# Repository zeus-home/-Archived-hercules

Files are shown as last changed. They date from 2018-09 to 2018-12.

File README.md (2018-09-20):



# Hercules

Hercules is responsible for actually executing the changes in the state of the devices according to the data collected by mercury and decision taken by the tesseract.

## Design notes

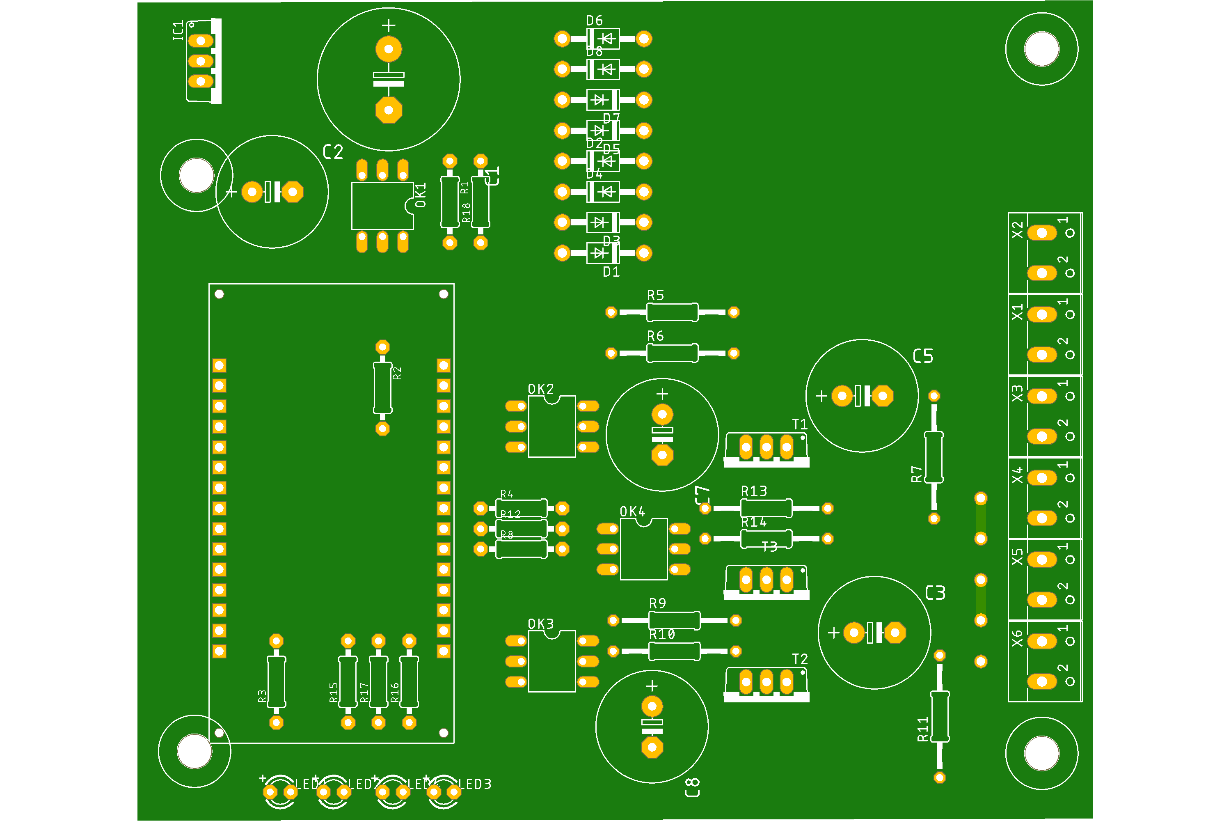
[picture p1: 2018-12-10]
hardware/iotssbv2_t.png

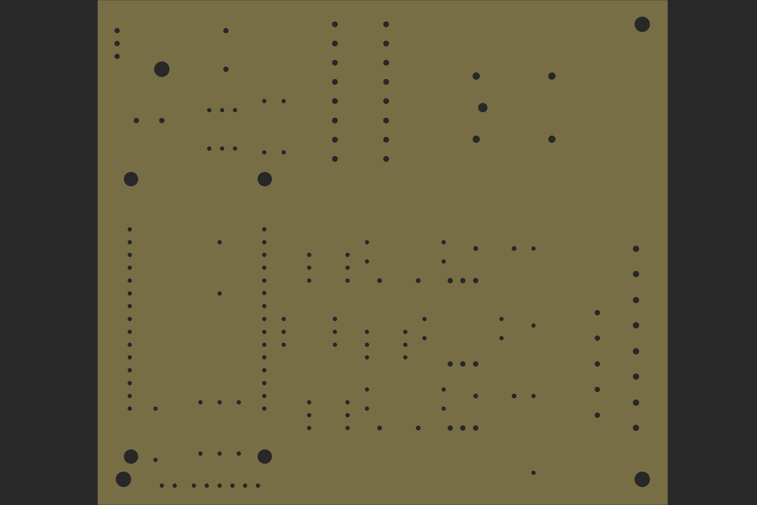
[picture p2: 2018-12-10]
hardware/iotssb_d.png

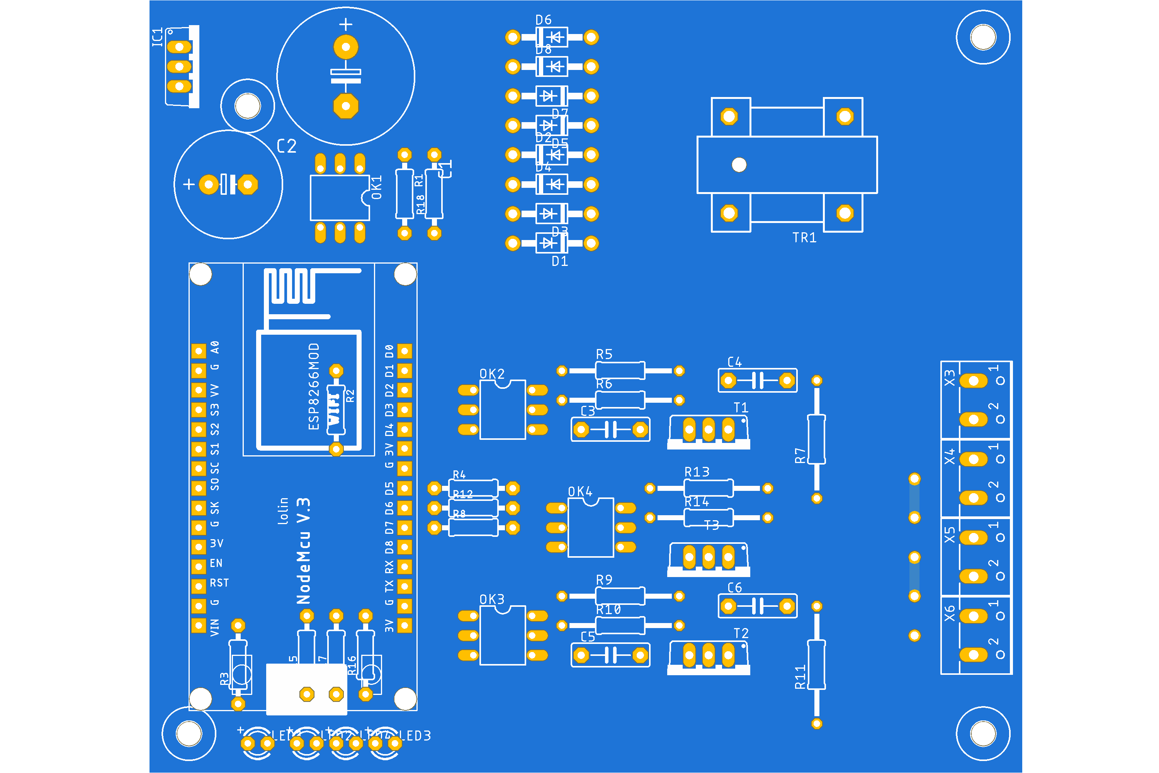
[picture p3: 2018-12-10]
hardware/iotssb_t.png

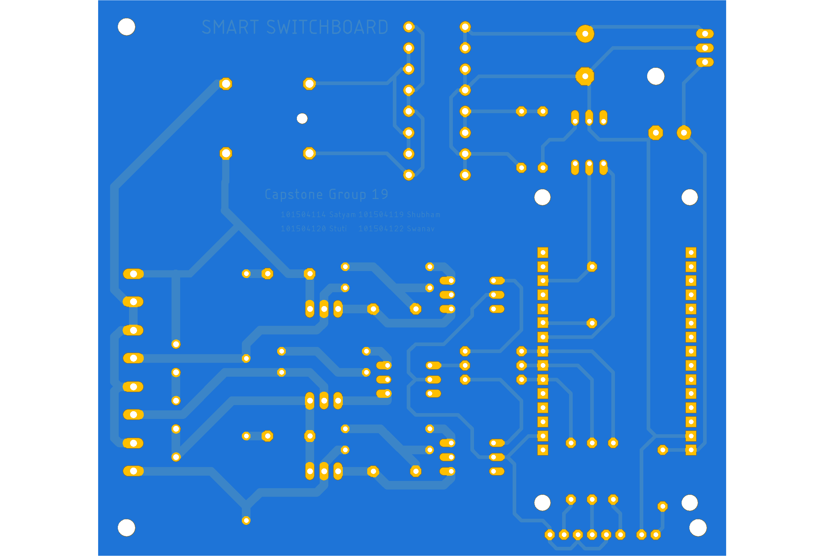
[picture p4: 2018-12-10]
hardware/iotssb_b.png

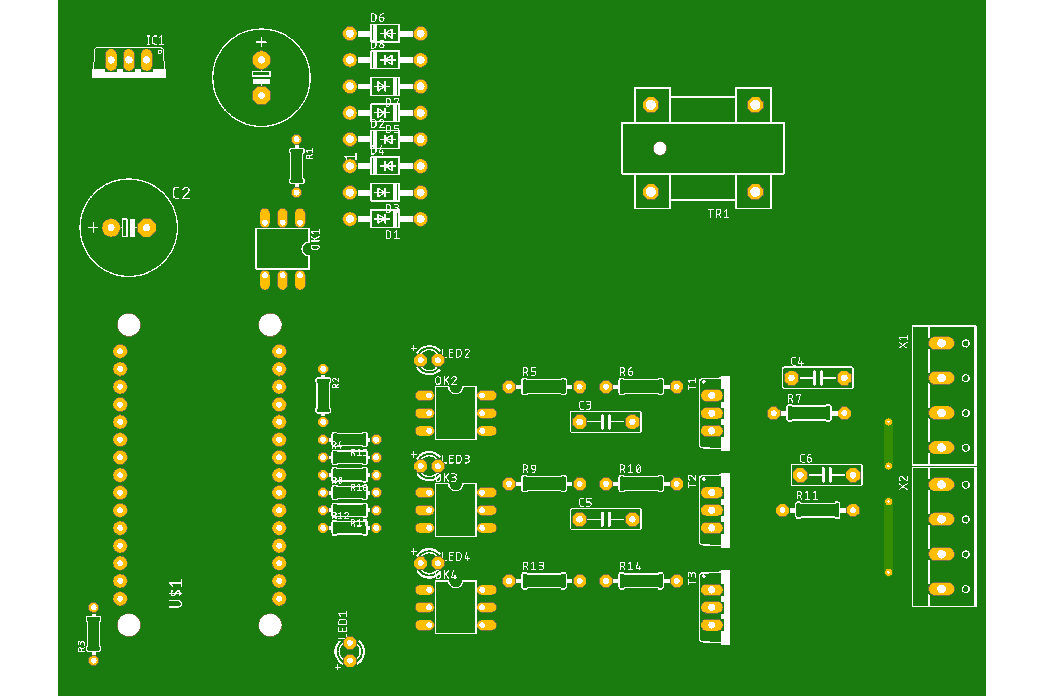
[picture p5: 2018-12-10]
hardware/v2.png

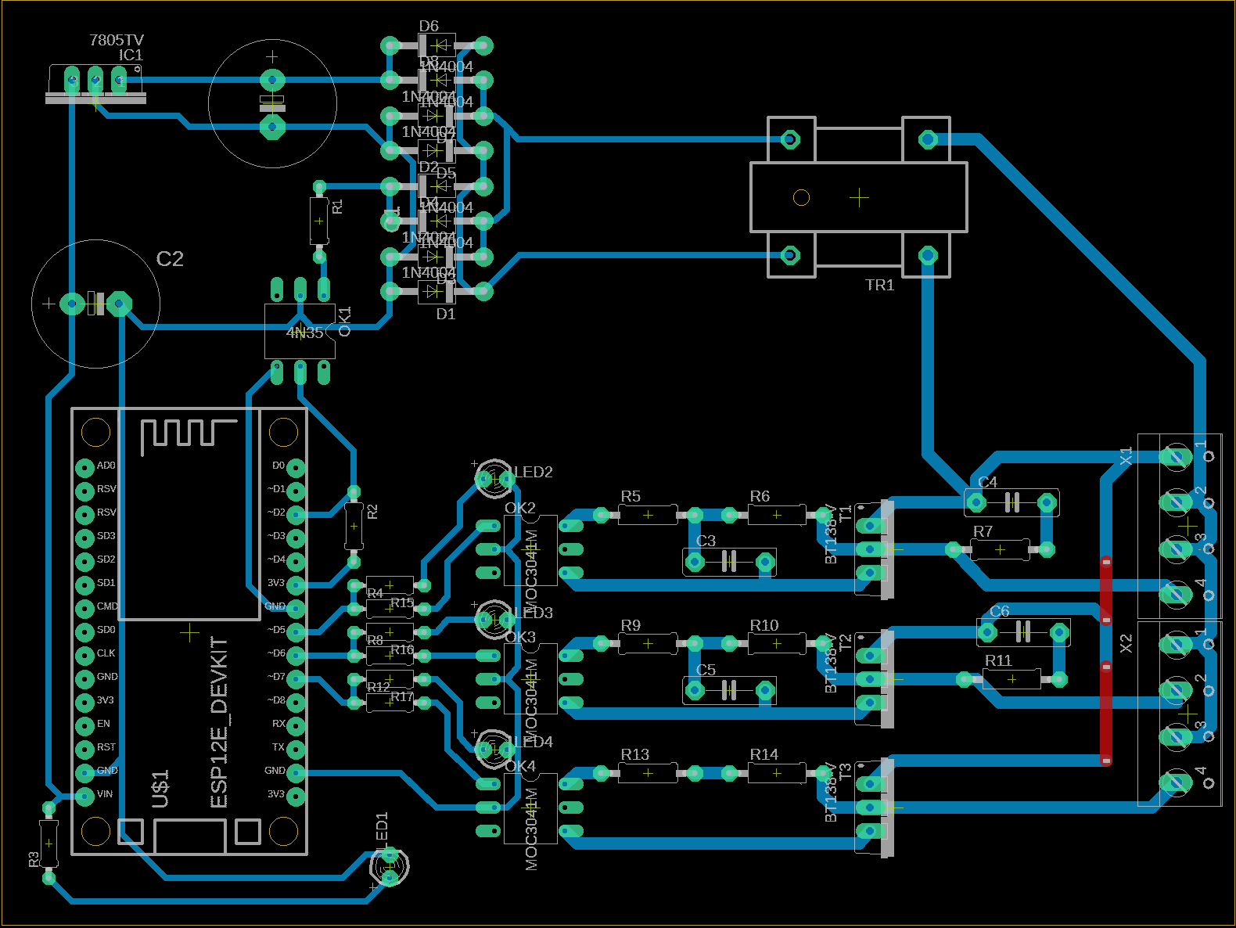
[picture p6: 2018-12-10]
hardware/PCB.png

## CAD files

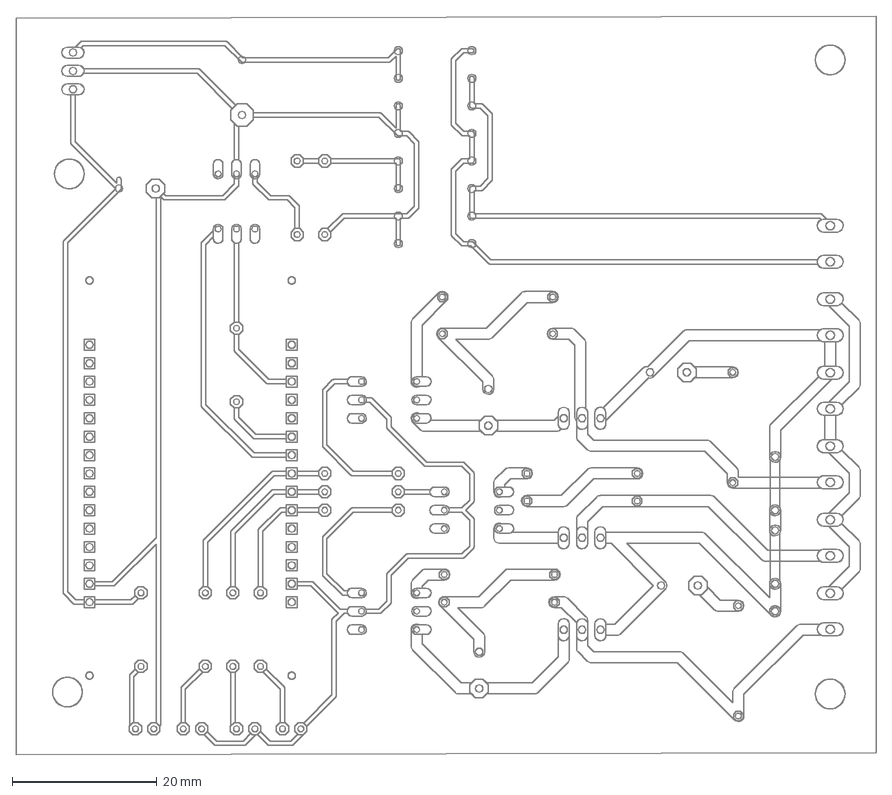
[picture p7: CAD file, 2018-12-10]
hardware/CAMOutputs/DrawingFiles/iotssb.dxf
118.9 x 102.0 mm

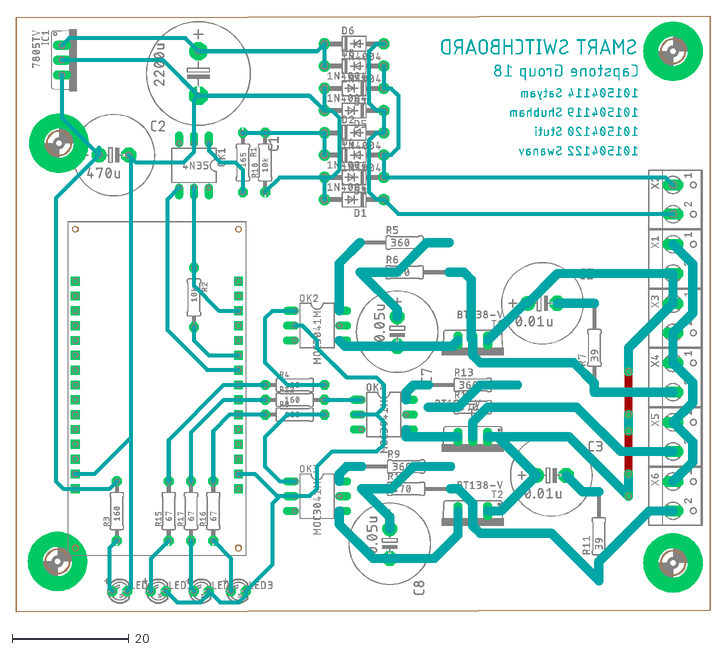
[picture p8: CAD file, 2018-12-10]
hardware/iotssb.dxf
118.9 x 102.0

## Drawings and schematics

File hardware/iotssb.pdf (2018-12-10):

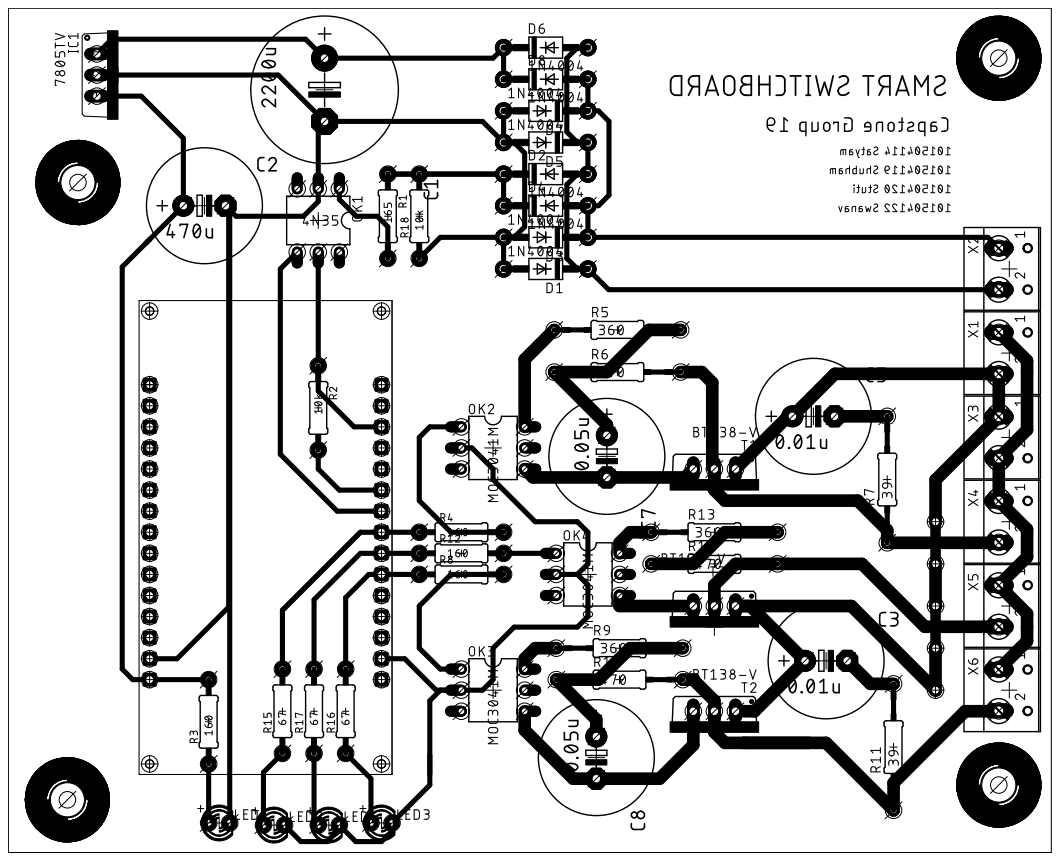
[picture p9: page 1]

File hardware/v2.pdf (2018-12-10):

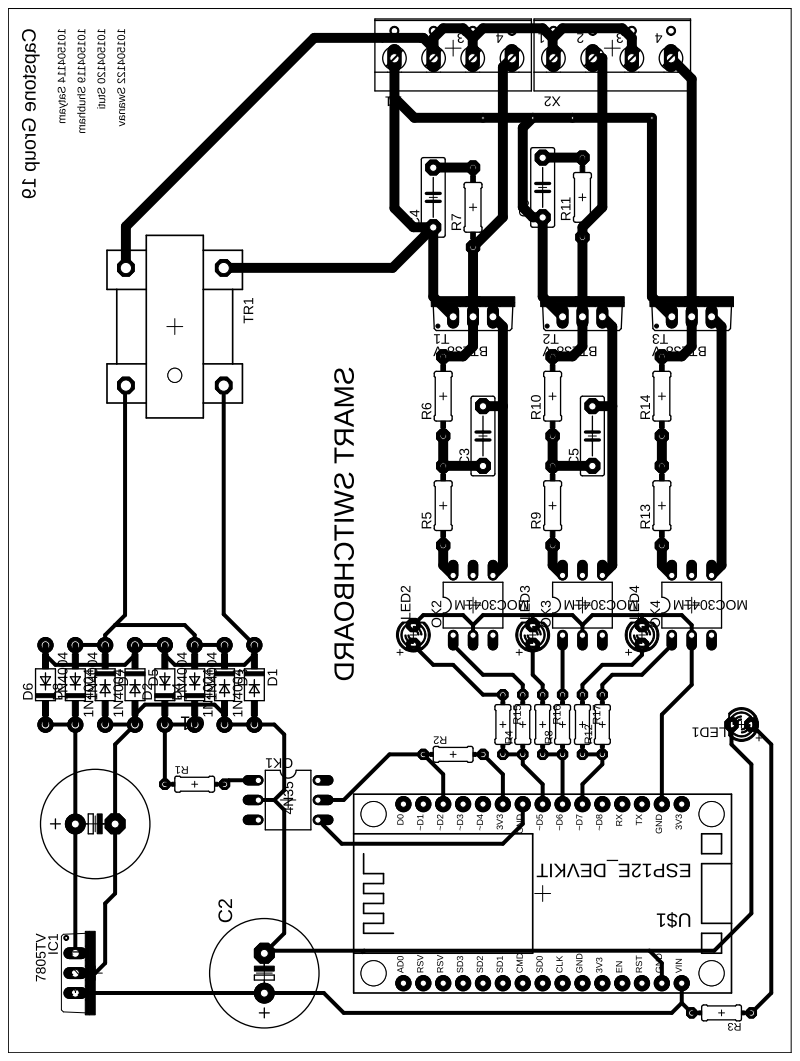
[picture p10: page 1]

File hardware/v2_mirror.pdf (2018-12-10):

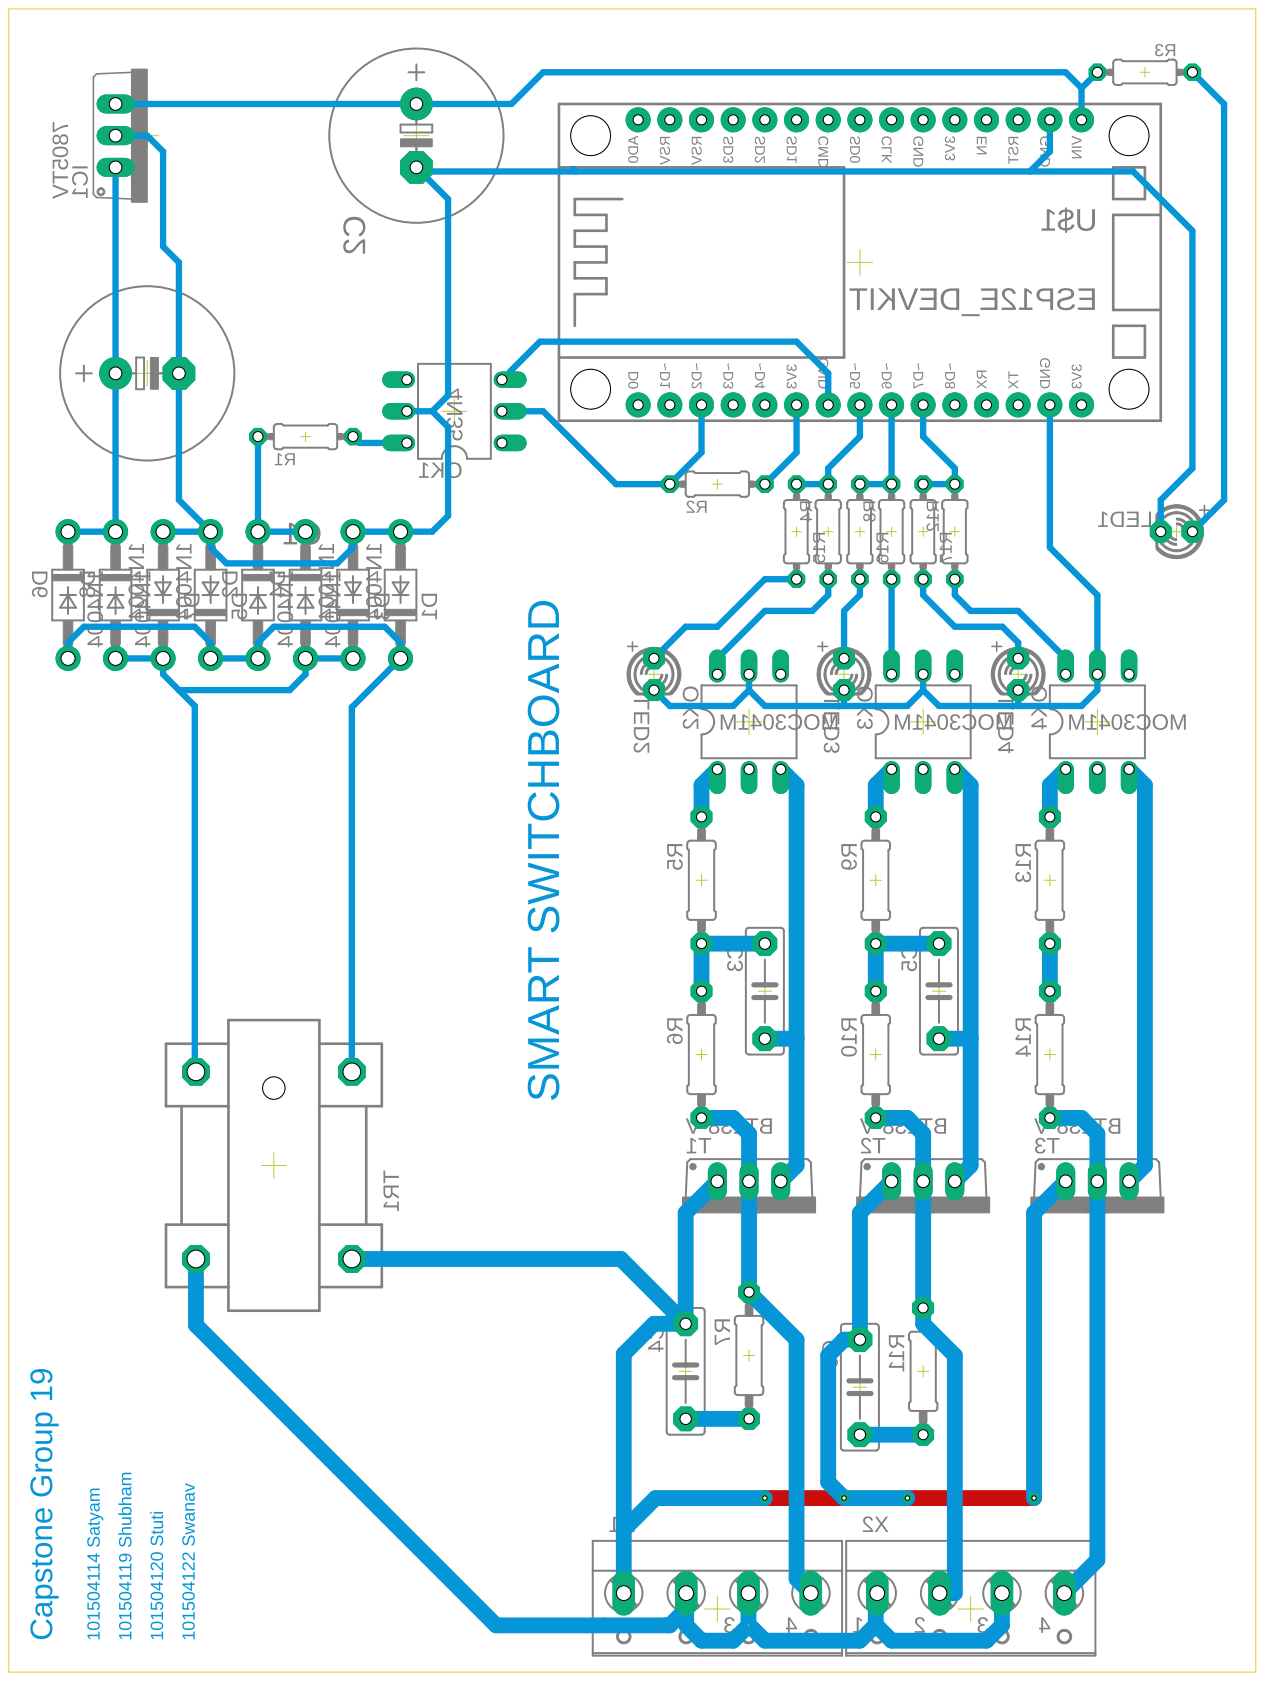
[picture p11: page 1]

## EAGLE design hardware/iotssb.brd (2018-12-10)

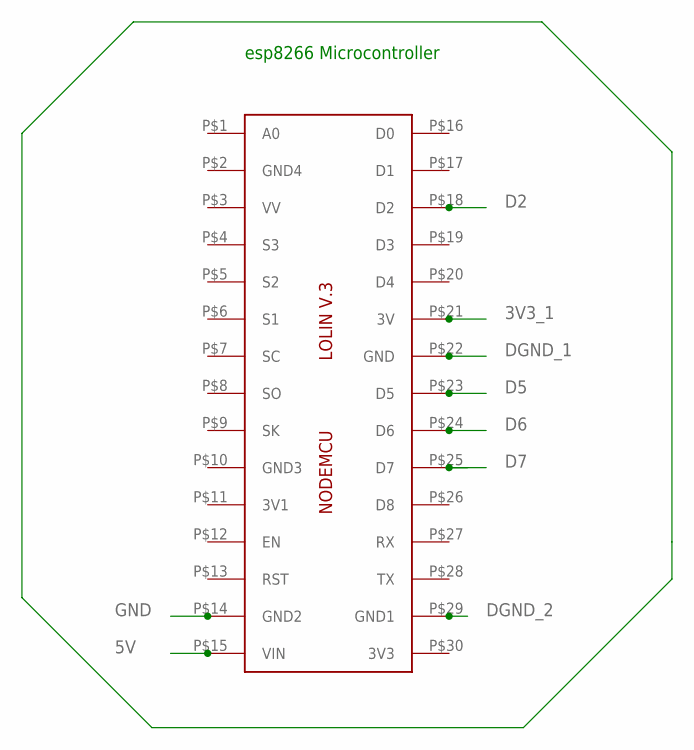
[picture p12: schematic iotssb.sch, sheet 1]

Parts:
IC2: LOLINV3ESP12E; LOL1NV0.1

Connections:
3V3_1: IC2.P$21 (3V); also elsewhere on the board
5V: IC2.P$15 (VIN); also elsewhere on the board
D2: IC2.P$18 (D2); also elsewhere on the board
D5: IC2.P$23 (D5); also elsewhere on the board
D6: IC2.P$24 (D6); also elsewhere on the board
D7: IC2.P$25 (D7); also elsewhere on the board
DGND_1: IC2.P$22 (GND); also elsewhere on the board
DGND_2: IC2.P$29 (GND1); also elsewhere on the board
GND: IC2.P$14 (GND2); also elsewhere on the board

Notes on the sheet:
esp8266 Microcontroller

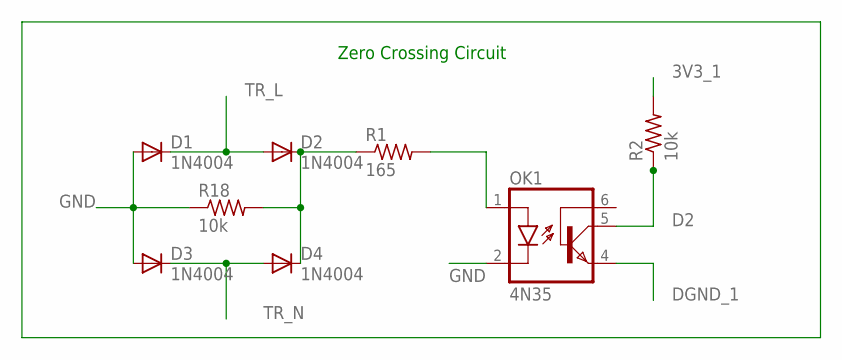
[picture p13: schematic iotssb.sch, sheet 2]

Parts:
D1, D2, D3, D4: 1N4004; DO41-10
OK1: 4N35; DIL06
R1: 165; 0207/10
R2, R18: 10k; 0207/10

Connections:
3V3_1: R2.2; also elsewhere on the board
D2: OK1.5 (COL), R2.1; also elsewhere on the board
DGND_1: OK1.4 (EMI); also elsewhere on the board
GND: D1.A, D3.A, OK1.2 (C), R18.1; also elsewhere on the board
unnamed: D2.C, D4.C, R1.1, R18.2
unnamed: OK1.1 (A), R1.2
TR_L: D1.C, D2.A; also elsewhere on the board
TR_N: D3.C, D4.A; also elsewhere on the board

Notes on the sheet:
Zero Crossing Circuit

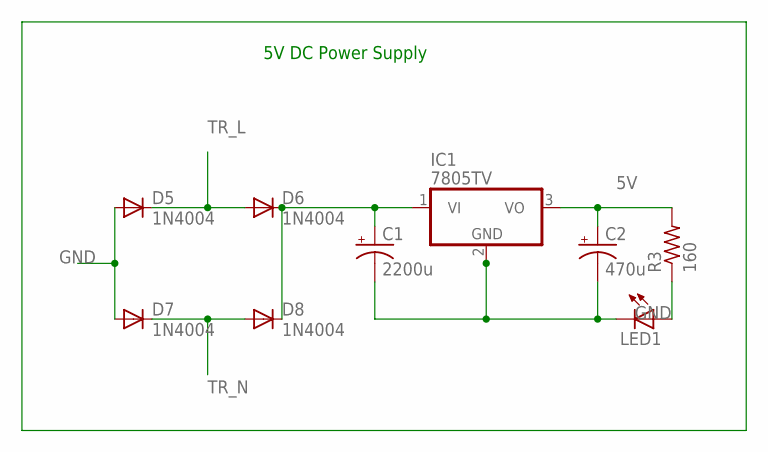
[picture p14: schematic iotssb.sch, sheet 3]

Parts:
C1: 2200u; E7,5-18
C2: 470u; E5-13
D5, D6, D7, D8: 1N4004; DO41-10
IC1: 7805TV; TO220V
LED1: LED3MM
R3: 160; 0207/10

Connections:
5V: C2.+, IC1.3 (VO), R3.2; also elsewhere on the board
GND: C1.-, C2.-, D5.A, D7.A, IC1.2 (GND), LED1.K (C); also elsewhere on the board
unnamed: C1.+, D6.C, D8.C, IC1.1 (VI)
unnamed: LED1.A, R3.1
TR_L: D5.C, D6.A; also elsewhere on the board
TR_N: D7.C, D8.A; also elsewhere on the board

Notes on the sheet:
5V DC Power Supply

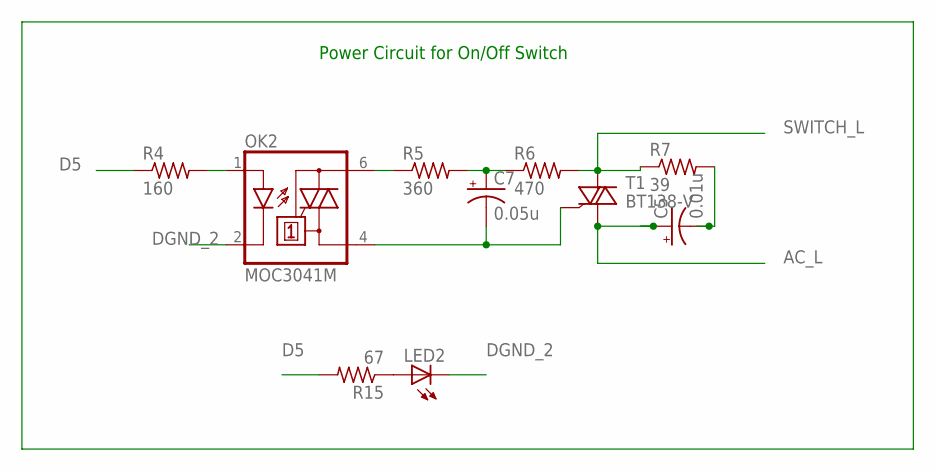
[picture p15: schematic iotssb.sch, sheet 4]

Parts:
C5: 0.01u; E5-13
C7: 0.05u; E5-13
LED2: LED3MM
OK2: MOC3041M; DIL06
R4: 160; 0207/10
R5: 360; 0207/15
R6: 470; 0207/15
R7: 39; 0207/15
R15: 67; 0207/10
T1: BT138-V; TO220BV

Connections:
AC_L: C5.+, T1.T1 (A1); also elsewhere on the board
D5: R4.1, R15.2; also elsewhere on the board
DGND_2: LED2.K (C), OK2.2 (C); also elsewhere on the board
unnamed: OK2.6 (A2), R5.1
unnamed: C7.-, OK2.4 (A1), T1.G
unnamed: OK2.1 (A), R4.2
unnamed: C7.+, R5.2, R6.1
unnamed: C5.-, R7.2
unnamed: LED2.A, R15.1
SWITCH_L: R6.2, R7.1, T1.T2 (A2); also elsewhere on the board

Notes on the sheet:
Power Circuit for On/Off Switch

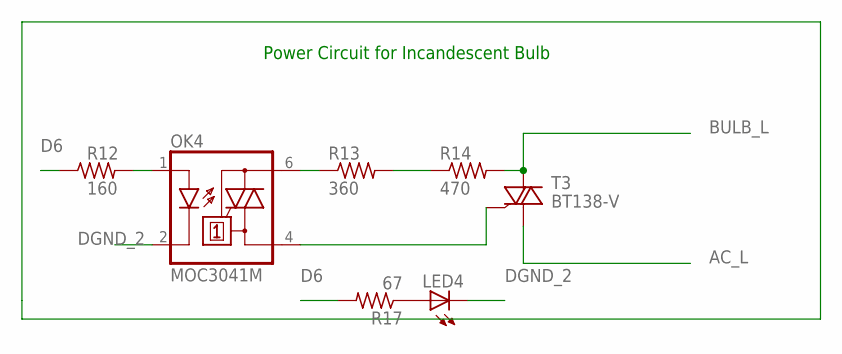
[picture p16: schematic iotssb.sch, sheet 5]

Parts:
LED4: LED3MM
OK4: MOC3041M; DIL06
R12: 160; 0207/10
R13: 360; 0207/15
R14: 470; 0207/15
R17: 67; 0207/10
T3: BT138-V; TO220BV

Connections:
AC_L: T3.T1 (A1); also elsewhere on the board
BULB_L: R14.2, T3.T2 (A2); also elsewhere on the board
D6: R12.1, R17.2; also elsewhere on the board
DGND_2: LED4.K (C), OK4.2 (C); also elsewhere on the board
unnamed: OK4.4 (A1), T3.G
unnamed: OK4.1 (A), R12.2
unnamed: OK4.6 (A2), R13.1
unnamed: R13.2, R14.1
unnamed: LED4.A, R17.1

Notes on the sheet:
Power Circuit for Incandescent Bulb

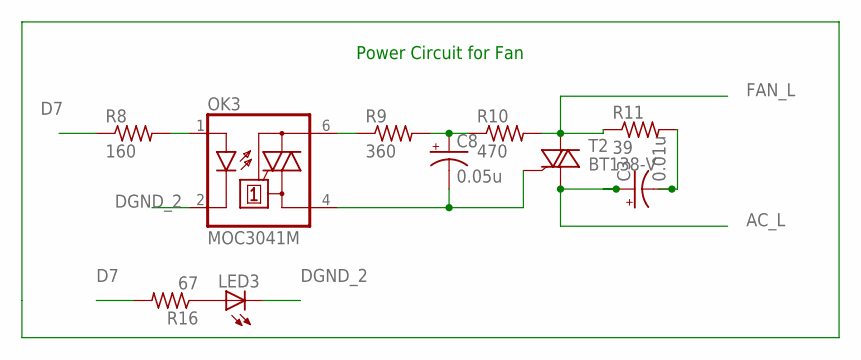
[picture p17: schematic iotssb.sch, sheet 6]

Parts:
C3: 0.01u; E5-13
C8: 0.05u; E5-13
LED3: LED3MM
OK3: MOC3041M; DIL06
R8: 160; 0207/10
R9: 360; 0207/15
R10: 470; 0207/15
R11: 39; 0207/15
R16: 67; 0207/10
T2: BT138-V; TO220BV

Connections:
AC_L: C3.+, T2.T1 (A1); also elsewhere on the board
D7: R8.1, R16.2; also elsewhere on the board
DGND_2: LED3.K (C), OK3.2 (C); also elsewhere on the board
FAN_L: R10.2, R11.1, T2.T2 (A2); also elsewhere on the board
unnamed: C8.-, OK3.4 (A1), T2.G
unnamed: OK3.1 (A), R8.2
unnamed: OK3.6 (A2), R9.1
unnamed: C8.+, R9.2, R10.1
unnamed: C3.-, R11.2
unnamed: LED3.A, R16.1

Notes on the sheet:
Power Circuit for Fan

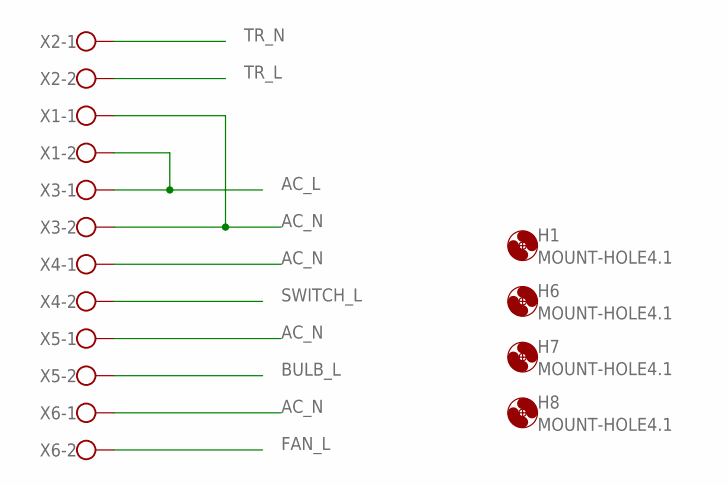
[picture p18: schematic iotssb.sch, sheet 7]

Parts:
H1, H6, H7, H8: MOUNT-HOLE4.1; 4,1
X1, X2, X3, X4, X5, X6: W237-102

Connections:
AC_L: X1.2, X3.1; also elsewhere on the board
AC_N: X1.1, X3.2, X4.1, X5.1, X6.1
BULB_L: X5.2; also elsewhere on the board
FAN_L: X6.2; also elsewhere on the board
SWITCH_L: X4.2; also elsewhere on the board
TR_L: X2.2; also elsewhere on the board
TR_N: X2.1; also elsewhere on the board

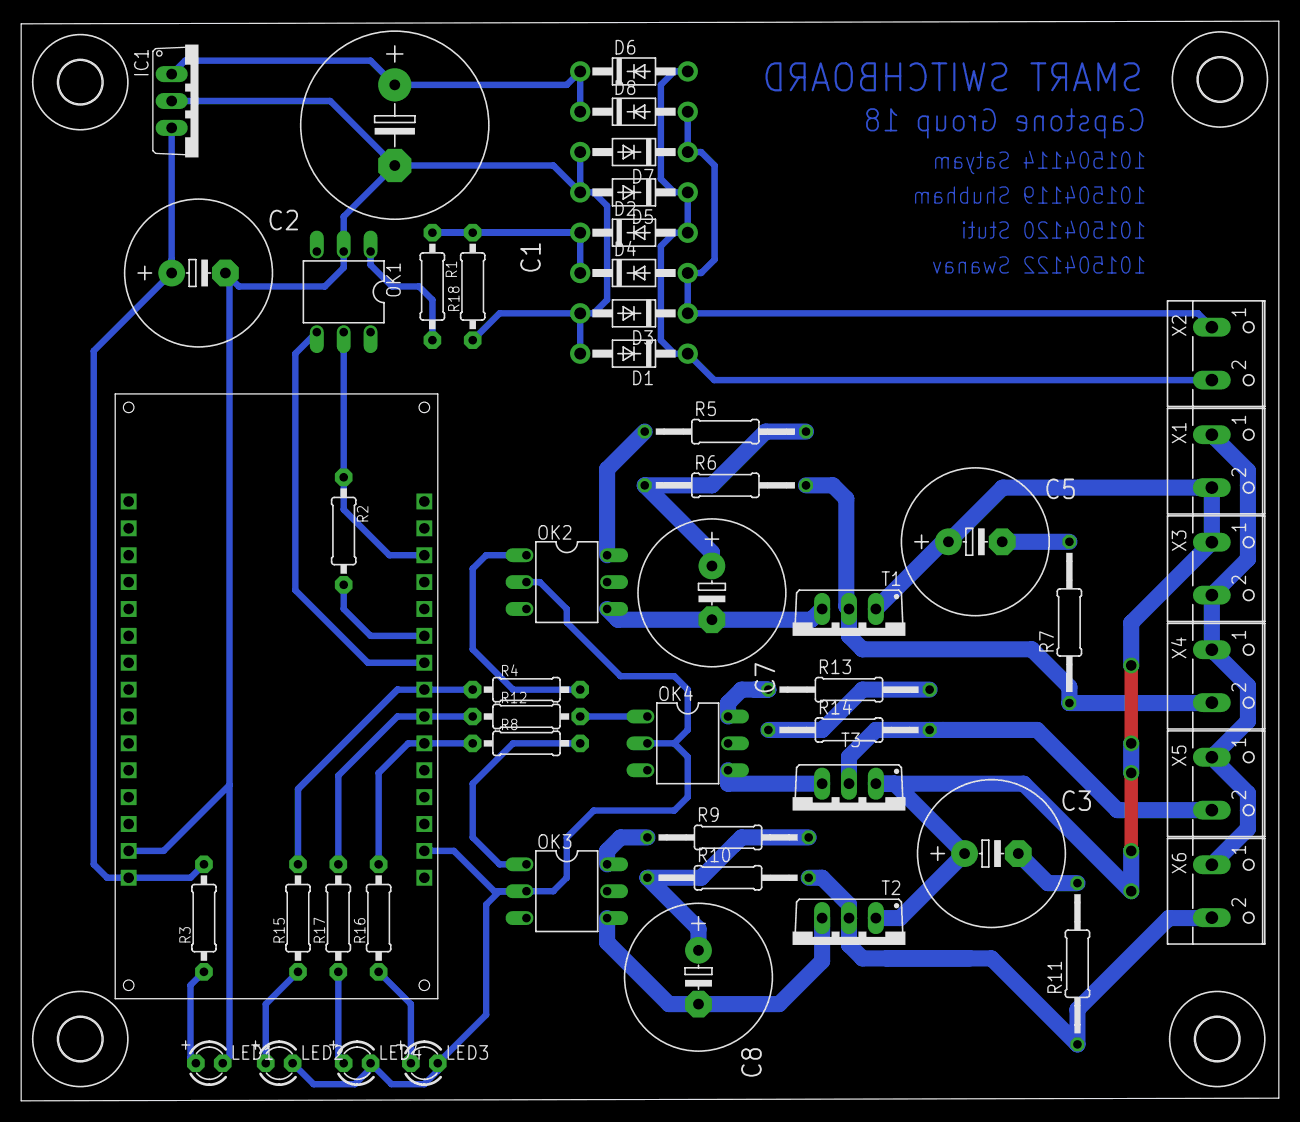
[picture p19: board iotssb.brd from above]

Board: 2 copper layers, 118.9 x 102.0 mm, 55 parts (0 on the bottom side), 37 nets.

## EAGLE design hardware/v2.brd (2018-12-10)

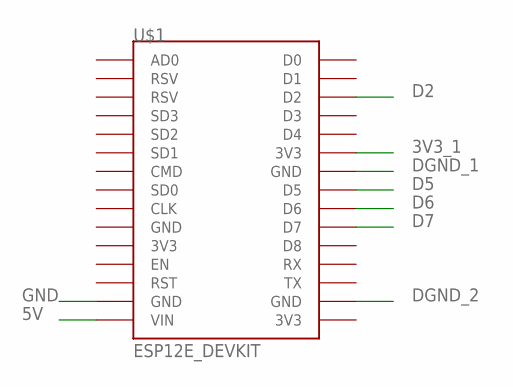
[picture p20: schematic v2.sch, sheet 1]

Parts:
U$1: ESP12E_DEVKIT

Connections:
3V3_1: U$1.3V3@1 (3V3); also elsewhere on the board
5V: U$1.VIN; also elsewhere on the board
D2: U$1.D2; also elsewhere on the board
D5: U$1.D5; also elsewhere on the board
D6: U$1.D6; also elsewhere on the board
D7: U$1.D7; also elsewhere on the board
DGND_1: U$1.GND@2 (GND); also elsewhere on the board
DGND_2: U$1.GND@3 (GND); also elsewhere on the board
GND: U$1.GND@1 (GND); also elsewhere on the board

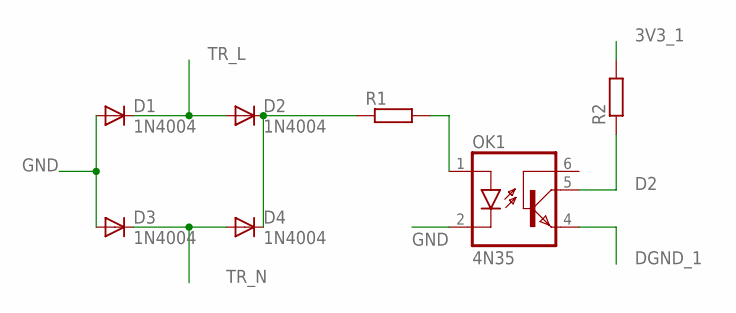
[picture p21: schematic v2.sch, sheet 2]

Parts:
D1, D2, D3, D4: 1N4004; DO41-10
OK1: 4N35; DIL06
R1, R2: R0204/7; 0204/7

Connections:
3V3_1: R2.2; also elsewhere on the board
D2: OK1.5 (COL), R2.1; also elsewhere on the board
DGND_1: OK1.4 (EMI); also elsewhere on the board
GND: D1.A, D3.A, OK1.2 (C); also elsewhere on the board
unnamed: D2.C, D4.C, R1.1
unnamed: OK1.1 (A), R1.2
TR_L: D1.C, D2.A; also elsewhere on the board
TR_N: D3.C, D4.A; also elsewhere on the board

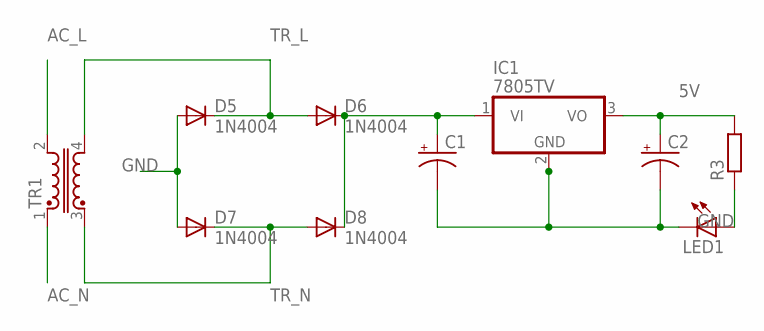
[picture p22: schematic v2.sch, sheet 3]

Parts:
C1, C2: CPOL-USE5-13; E5-13
D5, D6, D7, D8: 1N4004; DO41-10
IC1: 7805TV; TO220V
LED1: LED3MM
R3: R0204/7; 0204/7
TR1: U15-TRANSFORMER; U15

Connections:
5V: C2.+, IC1.3 (VO), R3.2; also elsewhere on the board
AC_L: TR1.2; also elsewhere on the board
AC_N: TR1.1; also elsewhere on the board
GND: C1.-, C2.-, D5.A, D7.A, IC1.2 (GND), LED1.K (C); also elsewhere on the board
unnamed: C1.+, D6.C, D8.C, IC1.1 (VI)
unnamed: LED1.A, R3.1
TR_L: D5.C, D6.A, TR1.4; also elsewhere on the board
TR_N: D7.C, D8.A, TR1.3; also elsewhere on the board

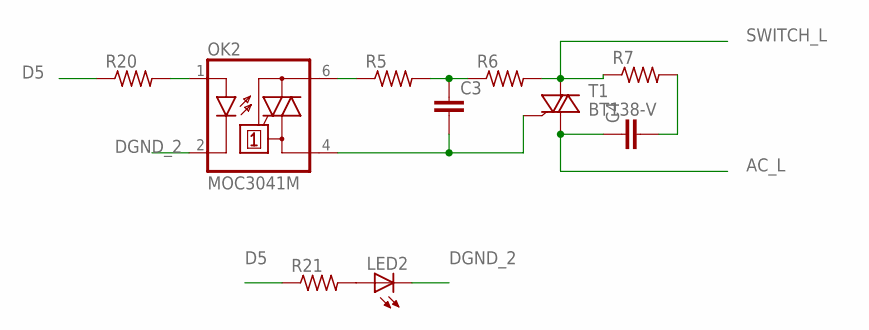
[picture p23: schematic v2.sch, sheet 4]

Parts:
C3, C4: C7.5/3; C7.5B3
LED2: LED3MM
OK2: MOC3041M; DIL06
R5, R6, R7, R20, R21: R-US_0207/10; 0207/10
T1: BT138-V; TO220BV

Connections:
AC_L: C4.1, T1.T1 (A1); also elsewhere on the board
D5: R20.1, R21.1; also elsewhere on the board
DGND_2: LED2.K (C), OK2.2 (C); also elsewhere on the board
unnamed: OK2.6 (A2), R5.1
unnamed: C3.2, OK2.4 (A1), T1.G
unnamed: OK2.1 (A), R20.2
unnamed: C3.1, R5.2, R6.1
unnamed: C4.2, R7.2
unnamed: LED2.A, R21.2
SWITCH_L: R6.2, R7.1, T1.T2 (A2); also elsewhere on the board


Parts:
C5, C6: C7.5/3; C7.5B3
LED3: LED3MM
OK3: MOC3041M; DIL06
R9, R10, R11, R12, R17: R-US_0207/10; 0207/10
T2: BT138-V; TO220BV

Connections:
AC_L: C6.1, T2.T1 (A1); also elsewhere on the board
D6: R12.1, R17.1; also elsewhere on the board
DGND_2: LED3.K (C), OK3.2 (C); also elsewhere on the board
FAN_L: R10.2, R11.1, T2.T2 (A2); also elsewhere on the board
unnamed: C5.2, OK3.4 (A1), T2.G
unnamed: OK3.1 (A), R12.2
unnamed: OK3.6 (A2), R9.1
unnamed: C5.1, R9.2, R10.1
unnamed: C6.2, R11.2
unnamed: LED3.A, R17.2


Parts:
LED4: LED3MM
OK4: MOC3041M; DIL06
R13, R14, R18, R19: R-US_0207/10; 0207/10
T3: BT138-V; TO220BV

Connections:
AC_L: T3.T1 (A1); also elsewhere on the board
BULB_L: R14.2, T3.T2 (A2); also elsewhere on the board
D7: R18.1, R19.1; also elsewhere on the board
DGND_2: LED4.K (C), OK4.2 (C); also elsewhere on the board
unnamed: OK4.4 (A1), T3.G
unnamed: OK4.1 (A), R18.2
unnamed: OK4.6 (A2), R13.1
unnamed: R13.2, R14.1
unnamed: LED4.A, R19.2

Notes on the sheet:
Power Circuit for Incandescent Bulb


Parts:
X3, X4, X5, X6: W237-102

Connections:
AC_L: X3.1; also elsewhere on the board
AC_N: X3.2, X4.1, X5.1, X6.1; also elsewhere on the board
BULB_L: X6.2; also elsewhere on the board
FAN_L: X5.2; also elsewhere on the board
SWITCH_L: X4.2; also elsewhere on the board


Board: 2 copper layers, 143.5 x 100.0 mm, 53 parts (0 on the bottom side), 37 nets.

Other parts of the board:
U$2, U$3, U$4, U$5: SK95-2M3

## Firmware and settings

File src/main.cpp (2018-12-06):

#include <Arduino.h>
#include <ESP8266WiFi.h>
#include <PubSubClient.h>

unsigned long zeroTime = 0;
int pulseWidth = 2;
int light_state = 0;
int fan_state = 0;

// WIFI SETTINGS
#define WIFI_SSID "OnePlus 6"
#define WIFI_PSK  "9821880713"

// MQTT SETTINGS
#define MQTT_SERVER "m15.cloudmqtt.com"
#define MQTT_PORT 13902
#define MQTT_USER "uglryohs"
#define MQTT_PASS "JKJlnLuvBN31"

#define TOPIC_LIGHT "hercules/sub/ESP_52F5B5/light"
#define TOPIC_FAN "hercules/sub/ESP_52F5B5/fan"
#define TOPIC_SWITCH "hercules/sub/ESP_52F5B5/switch"
#define TOPIC_PUB "message"

WiFiClient espClient;
PubSubClient client(espClient);

const int LED = D4;
const int Switch = D5;
const int Fan = D6;
const int Light = D7;

int fireDelay(int firingAngle) { 
  return (20*firingAngle)/360;
}

void toggle();
void onMessage(char* topic, byte* payload, unsigned int length);

void setup() {
  Serial.begin(9600);

  pinMode(LED, OUTPUT);
  pinMode(Light, OUTPUT);
  pinMode(Fan, OUTPUT);
  pinMode(Switch, OUTPUT);
  attachInterrupt(digitalPinToInterrupt(D2), toggle, RISING);

  WiFi.mode(WIFI_STA);
  WiFi.begin(WIFI_SSID, WIFI_PSK);
  Serial.println("Connecting");
  while(!WiFi.isConnected()) {
      Serial.print(".");
      delay(100);
  }
  Serial.println("\nConnected to WiFi Network");

  client.setServer(MQTT_SERVER, MQTT_PORT);
  client.setCallback(onMessage);

  Serial.println("Attempting connection to Tesseract...");
  while(!client.connected()) {
      if(client.connect("ESP_52F5B5", MQTT_USER, MQTT_PASS)) {
          Serial.println("\nConnected!");
          client.subscribe(TOPIC_LIGHT);
          client.subscribe(TOPIC_FAN);
          client.subscribe(TOPIC_SWITCH);
          client.publish(TOPIC_PUB, "Connection established");
      } else {
          Serial.print(".");
          delay(1000);
      }
  }
  digitalWrite(LED, LOW);
  Serial.println("Connected");

}

int firingAngle_light = 0;
int firingAngle_fan = 0;
unsigned long currentTime;

void loop() {
  currentTime = millis();
  int firingDelay_light = fireDelay(firingAngle_light);
  if(currentTime - zeroTime < firingDelay_light) {
    light_state = LOW;
  } else if(currentTime - zeroTime >= firingDelay_light && currentTime - zeroTime < firingDelay_light + pulseWidth) {
    light_state = HIGH;
  } else if(currentTime - zeroTime >= firingDelay_light + pulseWidth) {
    light_state = LOW;
  }
  // Serial.println(x);
  currentTime = millis();
  int firingDelay_fan = fireDelay(firingAngle_fan);
  if(currentTime - zeroTime < firingDelay_fan) {
    fan_state = LOW;
  } else if(currentTime - zeroTime >= firingDelay_fan && currentTime - zeroTime < firingDelay_fan + pulseWidth) {
    fan_state = HIGH;
  } else if(currentTime - zeroTime >= firingDelay_fan + pulseWidth) {
    fan_state = LOW;
  }

  digitalWrite(Light, light_state);
  digitalWrite(Fan, fan_state);

  client.loop();
  
}
void toggle() {
  zeroTime = millis();
}

void onMessage(char* topic, byte* payload, unsigned int length) {
    
    if(strcmp(topic,TOPIC_LIGHT)==0) {
      if(payload[0] == 'o') {
        if(payload[1] == 'f') {
          digitalWrite(Light, 0x00);
        }
      } else {
        int val = (int) payload[0] - 48;
        firingAngle_light = val*30;
      }
      Serial.print("Firing light: ");
      Serial.println(firingAngle_light);
    }

    if(strcmp(topic,TOPIC_FAN)==0) {
      if(payload[0] == 'o') {
        if(payload[1] == 'f') {
          digitalWrite(Fan, 0x00);
        }
      } else {
        int val = (int) payload[0] - 48;
        firingAngle_fan = val*30;
      }
      Serial.print("Firing fan: ");
      Serial.println(firingAngle_fan);
    }

    if(strcmp(topic,TOPIC_SWITCH)==0) {
      if(payload[0] == 'o') {
        if(payload[1] == 'f') {
          digitalWrite(Switch, 0x00);
        } else {
          digitalWrite(Switch, 0x01);
        }
      }
    }
}

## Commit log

2018-06-28 Switch Board Module created.
2018-06-28 README for Fan modified.
2018-08-12 Mqtt Implemented, with Reset button functionality.
2018-08-25 Indicator use timer instead of delay.
2018-08-25 Firing circuit.
2018-09-20 Fixed Reset Button definition.
    [main.cpp]
2018-09-20 Fixed Reset Button functionality.
    [main.cpp]
2018-12-10 Eagle Project added.
    [iotssb.brd, iotssb.dxf, iotssb.sch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]
